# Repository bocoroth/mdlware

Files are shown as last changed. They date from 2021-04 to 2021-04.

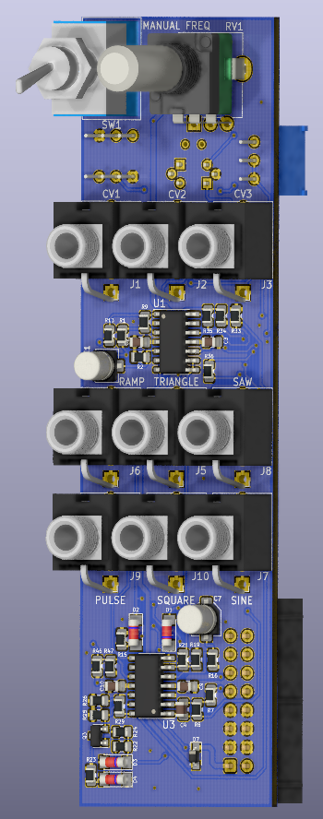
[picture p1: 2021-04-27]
MDLSynth/MDL-01 VCO/MDL-01 VCO-front.png

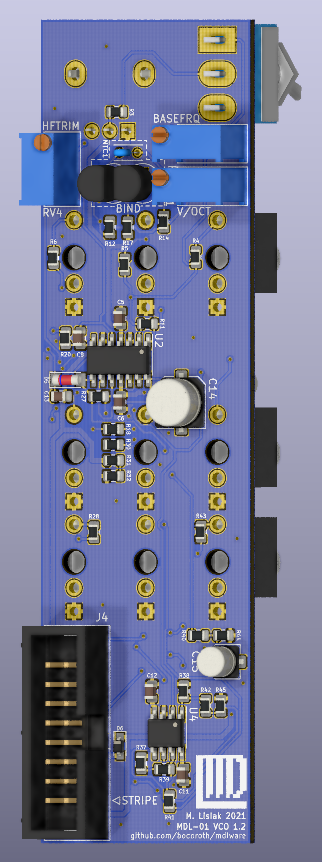
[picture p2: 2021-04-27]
MDLSynth/MDL-01 VCO/MDL-01 VCO-back.png

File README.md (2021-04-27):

# mdlware
OSHW projects

This repo contains my OSHW (Open Source Hardware) projects, generally created using LTSpice (for sims) and KiCad (for board layout). These projects are mostly related to Eurorack synthesizers.

These projects are released under the CERN-OHL-2.0-S license, which means they are free for anyone to use or make derivatives thereof, provided derivatives remain open source (i.e., no proprietary derivatives). See the LICENSE file for more information.

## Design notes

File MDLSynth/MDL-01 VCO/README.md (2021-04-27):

# MDL-01 VCO

A tracking Voltage Controlled Oscillator

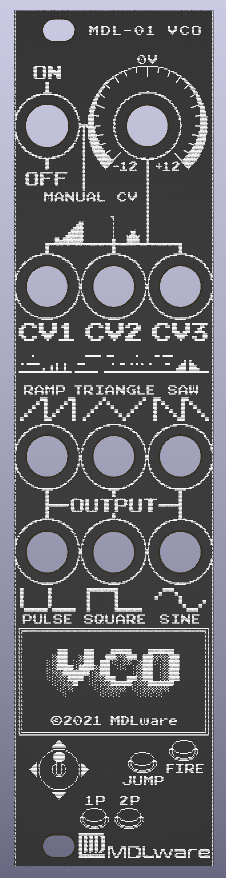
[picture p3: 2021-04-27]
MDLSynth/MDL-01 VCO/MDL-01 VCO-Panel.png

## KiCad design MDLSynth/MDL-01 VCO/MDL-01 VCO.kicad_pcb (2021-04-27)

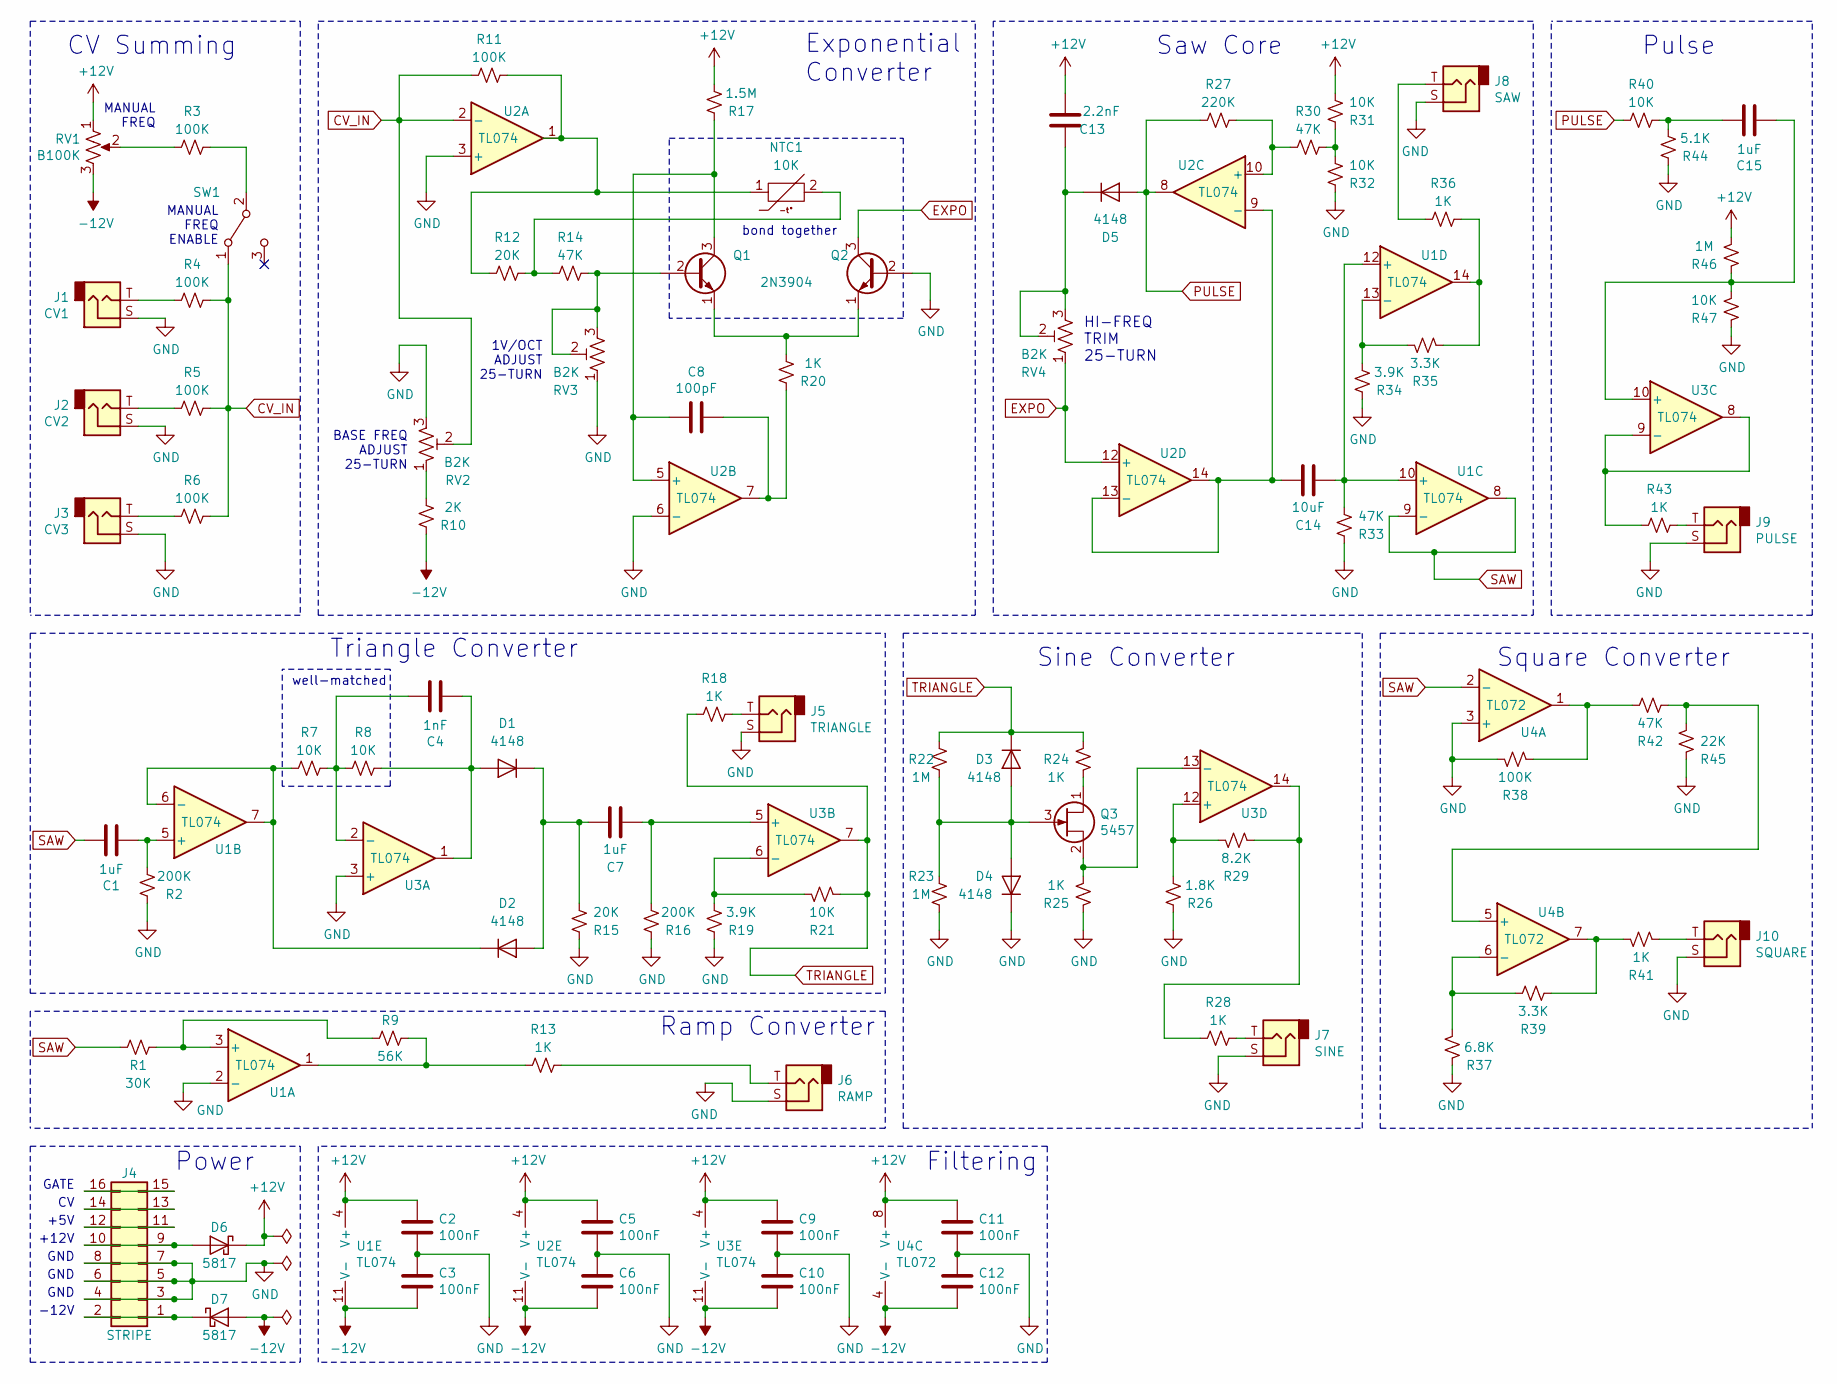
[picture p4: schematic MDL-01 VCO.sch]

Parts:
C1, C7, C15: 1uF; C_Elec_4x5.4; Digi-Key PCE4301CT-ND
C2, C3, C5, C6, C9, C10, C11, C12: 100nF; C_0805_2012Metric; Digi-Key 1276-2449-1-ND
C4: 1nF; C_0805_2012Metric; Digi-Key 1276-1020-1-ND
C8: 100pF; C_0805_2012Metric; Digi-Key 399-15000-1-ND
C13: 2.2nF; C_0805_2012Metric; Digi-Key 1276-2484-1-ND
C14: 10uF; C_Elec_6.3x5.4; Digi-Key PCE4294CT-ND
D1, D2, D3, D4, D5: 4148; D_MiniMELF; Digi-Key FDLL4148-D87ZCT-ND
D6, D7: 5817; D_SOD-323_HandSoldering; Digi-Key B5817WS-TPMSCT-ND
J1: CV1; Thonkiconn; Digi-Key --
J2: CV2; Thonkiconn; Digi-Key --
J3: CV3; Thonkiconn; Digi-Key --
J4: STRIPE; IDC-Header_2x08_P2.54mm_Vertical; Digi-Key S9171-ND
J5: TRIANGLE; Thonkiconn; Digi-Key --
J6: RAMP; Thonkiconn; Digi-Key --
J7: SINE; Thonkiconn; Digi-Key --
J8: SAW; Thonkiconn; Digi-Key --
J9: PULSE; Thonkiconn; Digi-Key --
J10: SQUARE; Thonkiconn; Digi-Key --
NTC1: 10K; THERM_NXRT15WB333JA1B010; Digi-Key 490-7171-ND
Q1, Q2: 2N3904; TO-92; Digi-Key 2N3904-APCT-ND
Q3: 5457; SOT-23; Digi-Key MMBF5457CT-ND
R1: 30K; R_0805_2012Metric; Digi-Key 2019-RK73H2ATTD3002FCT-ND
R2, R16: 200K; R_0805_2012Metric; Digi-Key 2019-RK73H2ATTD2003FCT-ND
R3, R4, R5, R6, R11, R38: 100K; R_0805_2012Metric; Digi-Key 13-AC0805FR-7W100KLCT-ND
R7, R8, R21, R31, R32, R40, R47: 10K; R_0805_2012Metric; Digi-Key 2019-RK73H2ATTE1002FCT-ND
R9: 56K; R_0805_2012Metric; Digi-Key 2019-RK73H2ATTD5602FCT-ND
R10: 2K; R_0805_2012Metric; Digi-Key RNCP0805FTD2K00CT-ND
R12, R15: 20K; R_0805_2012Metric; Digi-Key 2019-RK73H2ATTD2002FCT-ND
R13, R18, R20, R24, R25, R28, R36, R41, R43: 1K; R_0805_2012Metric; Digi-Key 2019-RK73H2ATTD1001FCT-ND
R14, R30, R33, R42: 47K; R_0805_2012Metric; Digi-Key 2019-RK73H2ATTD4702FCT-ND
R17: 1.5M; R_0805_2012Metric; Digi-Key 2019-RK73H2ATTD1504FCT-ND
R19, R34: 3.9K; R_0805_2012Metric; Digi-Key 2019-RK73H2ATTD3901FCT-ND
R22, R23, R46: 1M; R_0805_2012Metric; Digi-Key 2019-RK73H2ATTD1004FCT-ND
R26: 1.8K; R_0805_2012Metric; Digi-Key 2019-RK73H2ATTD1801FCT-ND
R27: 220K; R_0805_2012Metric; Digi-Key RHM220KAECT-ND
R29: 8.2K; R_0805_2012Metric; Digi-Key 2019-RK73H2ATTD8201FCT-ND
R35, R39: 3.3K; R_0805_2012Metric; Digi-Key 2019-RK73H2ATTD3R30FCT-ND
R37: 6.8K; R_0805_2012Metric; Digi-Key 2019-RK73H2ATTD6801FCT-ND
R44: 5.1K; R_0805_2012Metric; Digi-Key 2019-RK73H2ATTD5101FCT-ND
R45: 22K; R_0805_2012Metric; Digi-Key 2019-RK73H2ATTD2202FCT-ND
RV1: B100K; Potentiometer_Alpha_RD901F-40-00D_Single_Vertical; Digi-Key --
RV2, RV3, RV4: B2K; Potentiometer_Bourns_3296W_Vertical; Digi-Key 490-2880-ND
SW1: MANUAL FREQ; SW_Toggle_Blue_wSlots; Digi-Key EG2350-ND
U1, U2, U3: TL074; SOIC-14_3.9x8.7mm_P1.27mm; Digi-Key 296-TL074HIDRCT-ND
U4: TL072; SOIC-8_3.9x4.9mm_P1.27mm; Digi-Key 296-52761-1-ND

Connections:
+12V: C2.1, C5.1, C9.1, C11.1, C13.1, D6.1 (K), R17.2, R31.2, R46.2, RV1.1, U1.4 (V+), U2.4 (V+), U3.4 (V+), U4.8 (V+)
-12V: C3.2, C6.2, C10.2, C12.2, D7.2 (A), R10.1, RV1.3, U1.11 (V-), U2.11 (V-), U3.11 (V-), U4.4 (V-)
CV_IN: R4.1, R5.1, R6.1, R11.2, RV2.2, SW1.1 (A), U2.2 (-)
EXPO: Q2.3 (C), RV4.1, U2.12 (+)
GND: C2.2, C3.1, C5.2, C6.1, C9.2, C10.1, C11.2, C12.1, D4.1 (K), J1.S, J2.S, J3.S, J4.3, J4.4, J4.5, J4.6, J4.7, J4.8, J5.S, J6.S, J7.S, J8.S, J9.S, J10.S, Q2.2 (B), R2.1, R15.1, R16.1, R19.1, R23.1, R25.1, R26.1, R32.1, R33.1, R34.1, R37.2, R38.1, R44.1, R45.2, R47.1, RV2.3, RV3.1, U1.2 (-), U2.3 (+), U2.6 (-), U3.3 (+), U4.3 (+)
unnamed: C1.2, R2.2, U1.5 (+)
unnamed: C4.1, R7.1, R8.2, U3.2 (-)
unnamed: C4.2, D1.2 (A), R8.1, U3.1
unnamed: C7.1, D1.1 (K), D2.2 (A), R15.2
unnamed: C7.2, R16.2, U3.5 (+)
unnamed: C8.1, Q1.3 (C), R17.1, U2.5 (+)
unnamed: C8.2, R20.1, U2.7
unnamed: C13.2, D5.1 (K), RV4.2, RV4.3
unnamed: C14.1, U2.9 (-), U2.13 (-), U2.14
unnamed: C14.2, R33.2, U1.10 (+), U1.12 (+)
unnamed: C15.1, R40.1, R44.2
unnamed: C15.2, R46.1, R47.2, U3.10 (+)
unnamed: D2.1 (K), R7.2, U1.6 (-), U1.7
unnamed: D3.2 (A), D4.2 (A), Q3.3 (G), R22.1, R23.2
unnamed: D6.2 (A), J4.9, J4.10
unnamed: D7.1 (K), J4.1, J4.2
unnamed: J1.T, R4.2
unnamed: J2.T, R5.2
unnamed: J3.T, R6.2
unnamed: J4.11, J4.12
unnamed: J4.13, J4.14
unnamed: J4.15, J4.16
unnamed: J5.T, R18.1
unnamed: J6.T, R13.1
unnamed: J7.T, R28.1
unnamed: J8.T, R36.2
unnamed: J9.T, R43.1
unnamed: J10.T, R41.1
unnamed: NTC1.1, R11.1, R12.2, U2.1
unnamed: NTC1.2, R12.1, R14.2
unnamed: Q1.1 (E), Q2.1 (E), R20.2
unnamed: Q1.2 (B), R14.1, RV3.2, RV3.3
unnamed: Q3.1 (D), R24.1
unnamed: Q3.2 (S), R25.2, U3.13 (-)
unnamed: R1.1, R9.2, U1.3 (+)
unnamed: R3.1, SW1.2 (B)
unnamed: R3.2, RV1.2
unnamed: R10.2, RV2.1
unnamed: R9.1, R13.2, U1.1
unnamed: R19.2, R21.2, U3.6 (-)
unnamed: R26.2, R29.2, U3.12 (+)
unnamed: R27.1, R30.2, U2.10 (+)
unnamed: R28.2, R29.1, U3.14
unnamed: R30.1, R31.1, R32.2
unnamed: R34.2, R35.2, U1.13 (-)
unnamed: R35.1, R36.1, U1.14
unnamed: R37.1, R39.1, U4.6 (-)
unnamed: R38.2, R42.1, U4.1
unnamed: R39.2, R41.2, U4.7
unnamed: R42.2, R45.1, U4.5 (+)
unnamed: R43.2, U3.8, U3.9 (-)
PULSE: D5.2 (A), R27.2, R40.2, U2.8
SAW: C1.1, R1.2, U1.8, U1.9 (-), U4.2 (-)
TRIANGLE: D3.1 (K), R18.2, R21.1, R22.2, R24.2, U3.7

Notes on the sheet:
MANUAL FREQ
bond together
1V/OCT ADJUST 25-TURN
MANUAL FREQ ENABLE
CV Summing
Exponential Converter
Saw Core
HI-FREQ TRIM 25-TURN
Triangle Converter
Square Converter
Filtering
Ramp Converter
+5V
GATE
+12V
GND
-12V
BASE FREQ ADJUST 25-TURN
Pulse
well-matched
Sine Converter
Power

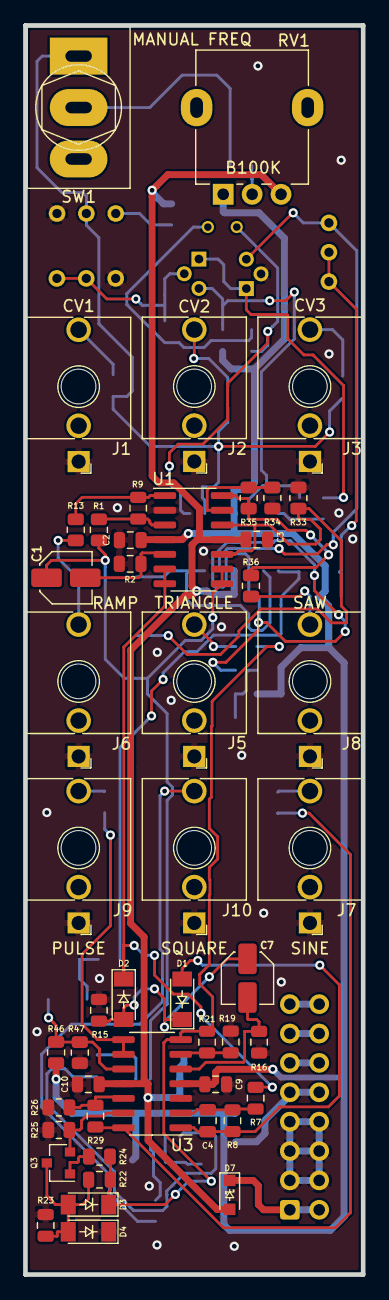
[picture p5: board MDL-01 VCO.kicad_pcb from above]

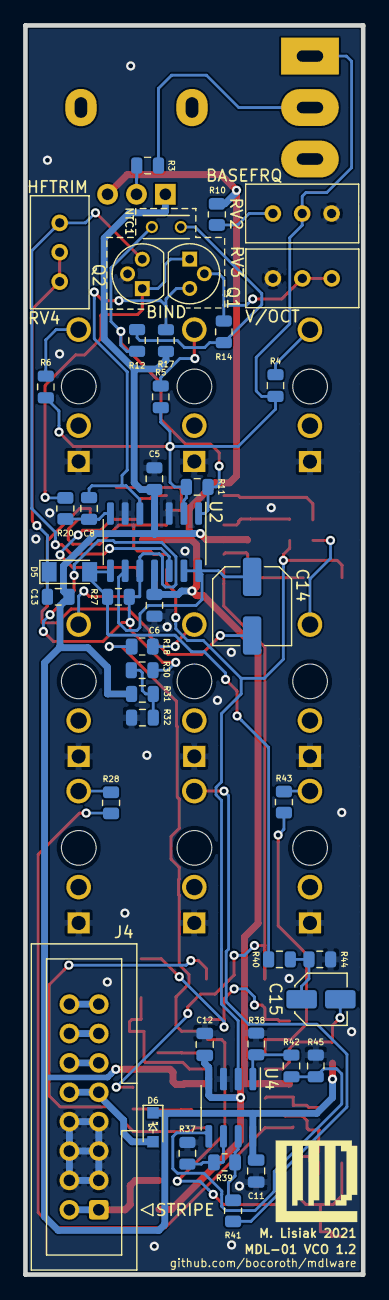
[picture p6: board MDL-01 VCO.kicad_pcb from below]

Board: 2 copper layers, 29.2 x 108.0 mm, 92 parts (44 on the bottom side), 59 nets.

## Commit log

2020-10-02 VCO initial version
    [VCO-Panel.kicad_pcb, VCO.kicad_pcb, VCO.sch]
2021-04-27 VCO v1.2
    [MDL-01 VCO-Panel (old).kicad_pcb, MDL-01 VCO-Panel.kicad_pcb, MDL-01 VCO.kicad_pcb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]
2021-04-27 codebase cleanup
    [VCO.kicad_pcb, VCO.sch]

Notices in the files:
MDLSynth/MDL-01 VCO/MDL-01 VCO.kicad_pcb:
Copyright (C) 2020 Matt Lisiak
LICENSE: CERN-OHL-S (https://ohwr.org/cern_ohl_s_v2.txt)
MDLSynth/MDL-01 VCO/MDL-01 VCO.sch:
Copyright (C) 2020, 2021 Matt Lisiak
